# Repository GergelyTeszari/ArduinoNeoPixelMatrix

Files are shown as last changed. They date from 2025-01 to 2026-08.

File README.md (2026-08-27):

# Arduino NeoPixel Matrix

A complete 16 × 16 RGB LED matrix project combining embedded firmware, serial image transfer, a custom desktop pixel-art editor, reusable static pictures, and a 3D-printable enclosure.

The project supports a compiled-in static image and two serial receiver variants for an Arduino Uno-controlled NeoPixel matrix. The repository also contains a Python/Tkinter editor, a curated set of Arduino-ready image snippets, hardware test sketches, and enclosure models.

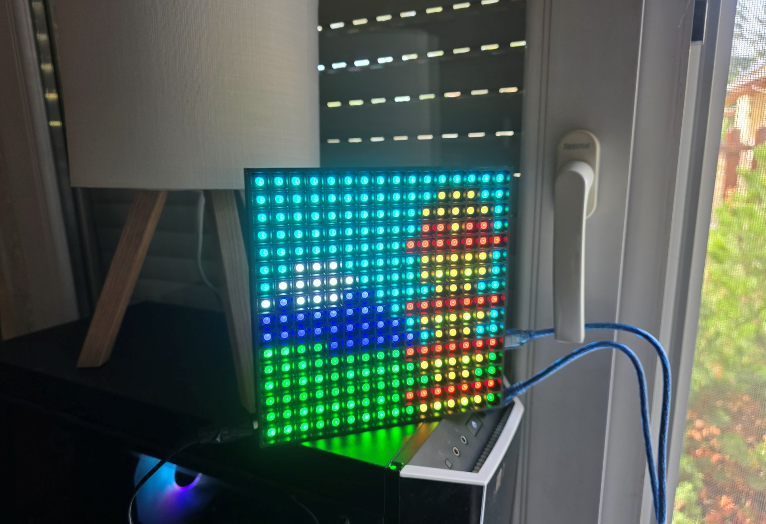
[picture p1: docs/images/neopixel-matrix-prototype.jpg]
16 x 16 NeoPixel matrix prototype displaying Mount Fuji and a pagoda


*The assembled prototype displaying the static Mount Fuji image included with the firmware.*

## Project overview

```mermaid
flowchart LR
    A[Python pixel editor] -->|TXT array rows| B[Static firmware]
    C[Desktop serial sender] -->|Pixel or row protocol| D[Serial firmware]
    B --> E[16 x 16 RGB matrix]
    D --> E
    F[3D-printable enclosure] --> E
```

This project brings together several engineering areas:

- embedded firmware development on Arduino Uno;
- coordinate transformation for a serpentine-wired LED matrix;
- a Python desktop tool for creating pixel art;
- static and serial image transfer workflows;
- custom image-data export and reusable picture sources;
- mechanical design for a printable enclosure and supporting parts.

## Current features

### Arduino firmware

- Controls a 16 × 16, 256-pixel RGB NeoPixel matrix.
- Maps two-dimensional image coordinates to the physical serpentine LED layout.
- Corrects the vertical orientation of the installed matrix.
- Displays a compiled-in static image, currently Mount Fuji and a pagoda.
- Includes a legacy receiver that accepts one `RRGGBB` pixel per serial line.
- Includes an optimized receiver that accepts one 16-pixel row per serial line.
- Includes full-matrix color and individual-pixel diagnostic sketches.
- Uses the Adafruit NeoPixel library.

### Pixel-art editor

The included `tools/pixel_editor/NeoPixel_Matrix_Canvas.py` application provides:

- a 16 × 16 drawing canvas;
- color selection;
- continuous mouse drawing;
- an eraser and canvas reset function;
- global brightness scaling before export;
- export as Arduino C array rows;
- export to the custom `.mtx` text format.

### Mechanical design

The `hardware/enclosure` directory contains STL files for:

- the upper frame and pixel-separating grid;
- the lower enclosure with hardware cut-outs;
- desktop support feet;
- an LED-position alignment template.

The enclosure is an early hardware revision and may require small adjustments depending on the exact matrix PCB and connector placement.

### Static picture gallery

`assets/patterns/txt` contains six 16 × 16 pictures as Arduino initializer rows. Keeping these generated `.txt` snippets makes it possible to replace the static `colorMatrix` without changing the exporter or introducing a build-time conversion step. See [Static image source files](docs/static-images.md).

## Repository structure

```text
ArduinoNeoPixelMatrix/
├── assets/patterns/txt/       # Arduino-ready 16 x 16 image snippets
├── docs/                      # Serial protocol and static image guides
├── examples/                  # Matrix hardware diagnostic sketches
├── firmware/
│   ├── serial/                # Legacy and optimized serial receivers
│   └── static_image/          # Compiled-in image firmware
├── hardware/enclosure/        # 3D-printable STL files
├── tools/pixel_editor/        # Python/Tkinter image editor
├── .gitignore
└── README.md
```

## Requirements

### Firmware

- Arduino Uno or compatible board
- 16 × 16 WS2812/NeoPixel-compatible RGB matrix
- Arduino IDE
- [Adafruit NeoPixel library](https://github.com/adafruit/Adafruit_NeoPixel)
- A suitable external 5 V power supply for the LED matrix

> **Power note:** A 256-pixel RGB matrix can require substantially more current than an Arduino board can safely provide. Power the matrix from a properly rated external supply and connect the supply ground to the Arduino ground.

### Pixel editor

- Python 3
- Tkinter, normally included with standard Python desktop installations

No third-party Python packages are currently required.

## Usage

### Static image workflow

Run the editor from the repository root:

```bash
python tools/pixel_editor/NeoPixel_Matrix_Canvas.py
```

Draw the image, select the required brightness, and choose **Export to TXT**.

The generated `export.txt` file contains the rows of an Arduino-compatible color matrix. Replace the contents of the `colorMatrix` initializer in:

```text
firmware/static_image/NeoPixel_Array/NeoPixel_Array.ino
```

with the exported rows. Existing ready-to-copy pictures are available in `assets/patterns/txt`; their exact format and names are described in [Static image source files](docs/static-images.md).

Open the sketch in Arduino IDE, install the Adafruit NeoPixel library if required, select the correct board and serial port, and upload the firmware.

The included example image is a hand-drawn Mount Fuji scene with a Japanese pagoda.

### Serial image workflow

Choose one of the following sketches:

- `firmware/serial/NeoPixel_Serial/NeoPixel_Serial.ino` receives and displays one pixel per line;
- `firmware/serial/NeoPixel_Serial_optimised/NeoPixel_Serial_optimised.ino` receives and displays one complete 16-pixel row per line.

The two sketches use different wire protocols. Read [Serial firmware and protocol](docs/serial-protocol.md) before implementing or selecting a sender. The optimized version is recommended for normal frame transfer; the legacy version remains available for compatibility and debugging.

### Hardware diagnostics

- `examples/NeoPixel_AllRGB_test/NeoPixel_AllRGB_test.ino` fills the complete matrix with red, green, blue and a pale white test color.
- `examples/NeoPixel_IndividualRGB_test/NeoPixel_IndividualRGB_test.ino` walks through every logical position one at a time in each RGB channel, making wiring-order and mapping errors easier to locate.

## Implementation details

The physical LEDs are arranged in alternating directions. The firmware converts logical `(x, y)` coordinates to the correct physical LED index:

```cpp
int getPixelIndex(int x, int y) {
  int invertedY = 15 - y;

  if (invertedY % 2 == 0) {
    return invertedY * 16 + x;
  }

  return invertedY * 16 + (15 - x);
}
```

This allows the image data to remain stored as a conventional two-dimensional array while the mapping function handles the physical wiring layout.

## Project status and limitations

This repository currently represents a working prototype rather than a finished product.

- The static Arduino firmware displays one image compiled into the sketch.
- Two serial receivers provide pixel-by-pixel and row-by-row image transfer.
- Serial transfer has no acknowledgement, checksum or atomic frame swap.
- The `.mtx` format can be exported by the editor but is not yet loaded by the firmware.
- The editor does not yet reopen existing `.mtx` files.
- Matrix dimensions and hardware pins are currently fixed in the source code.
- The static image representation is memory-intensive for an Arduino Uno.
- The enclosure is a first mechanical revision.

## Planned improvements

- Store image data more efficiently, for example in flash memory.
- Add an automated converter from the maintained TXT snippets to firmware headers.
- Add `.mtx` import to the desktop editor.
- Implement dynamic image loading on an ESP32-based version.
- Add framing, checksums and acknowledgements to serial image transfer.
- Add SD-card image loading.
- Make matrix dimensions, orientation, and pin assignment configurable.
- Add hardware photos, a wiring diagram, and a short demonstration video.
- Add automated checks for the Python exporter, picture dimensions, serial parser and coordinate mapping.

## Background

This is a personal end-to-end embedded project covering firmware, tooling, physical integration, and mechanical prototyping. Its main purpose is to explore how a small embedded product can be supported by purpose-built development tools instead of treating the firmware as an isolated sketch.

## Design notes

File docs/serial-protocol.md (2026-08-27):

# Serial firmware and protocol

The repository contains two Arduino sketches that receive a 16 x 16 RGB image
over a 115200 baud serial connection. Both expect colors in six-character
`RRGGBB` hexadecimal notation and both map ordinary top-left-origin image
coordinates to the installed serpentine matrix wiring.

The protocols are deliberately documented separately because they are not
interchangeable.

## Quick comparison

| Behavior | Legacy receiver | Optimized receiver |
| --- | --- | --- |
| Sketch | `NeoPixel_serial` | `NeoPixel_serial_optimised` |
| Data per line | One pixel, 6 characters | One row, 96 characters |
| Data lines per frame | 256 | 16 |
| `strip.show()` calls per frame | 256 | 16 |
| Reset recognition | Any 10-character line | Exactly `0123456789` |
| Reset clears LEDs | Yes | No |
| Invalid input | Ignored by length | Ignored by length/content |

Use the optimized receiver for normal image transfer. The legacy version is
kept for compatibility with an older sender and is useful when watching an
image arrive one pixel at a time.

## Shared configuration

- Baud rate: `115200`
- Color format: `RRGGBB`, without `#` or separators
- Logical dimensions: 16 columns by 16 rows
- Logical order: top row to bottom row, left to right within each row
- Data pin: Arduino digital pin 6
- LED type: `NEO_GRB + NEO_KHZ800`

For example, the following values represent individual pixels:

```text
FF0000  red
00FF00  green
0000FF  blue
000000  off
FFFFFF  white
```

Although data is expressed as RGB, the Adafruit NeoPixel library handles the
matrix's physical GRB channel order.

## Legacy pixel-by-pixel receiver

Sketch:
`firmware/serial/NeoPixel_Serial/NeoPixel_Serial.ino`

### Starting a frame

Send one line containing exactly ten characters. For compatibility with the
original implementation, the actual characters are not checked. Using the
same token as the optimized protocol is recommended:

```text
0123456789
```

The receiver then:

1. moves its logical write cursor to pixel 0;
2. clears all 256 LEDs;
3. displays the cleared matrix immediately.

### Sending pixels

Send 256 lines. Each line contains exactly one six-character color:

```text
FF0000
00FF00
0000FF
...
```

The first line writes logical coordinate `(0, 0)`, the second `(1, 0)`, and so
on. After `(15, 0)`, the next value writes `(0, 1)`. Each accepted value is
shown immediately. Values sent after the 256th pixel are ignored until another
reset line arrives.

The legacy sketch accepts either LF or CRLF line endings. It uses Arduino
`String` and refreshes after every pixel, so it is less memory- and
bandwidth-efficient than the optimized version.

## Optimized row-by-row receiver

Sketch:
`firmware/serial/NeoPixel_Serial_optimised/NeoPixel_Serial_optimised.ino`

### Starting a frame

Send this exact line:

```text
0123456789
```

This resets the logical row cursor to row 0. It intentionally does not clear
the LEDs, allowing the old image to remain visible while the new frame arrives.

### Sending rows

Send exactly 16 lines after the reset. Each line contains 16 adjacent `RRGGBB`
values with no spaces or separators, for a total of 96 characters:

```text
FF000000FF000000FF000000FF000000FF000000FF000000FF000000FFFFFF
```

That example is one row containing 16 pixels. The firmware validates the row
length and hexadecimal characters, fills all 16 pixels, then calls
`strip.show()` once. Invalid rows are ignored without advancing the row cursor.

After 16 valid rows, further row data is ignored until the reset command is
received. Both LF and CRLF line endings are accepted.

## Minimal Python sender outline

The important part of a sender is to preserve row-major ordering and terminate
every command or data record with a newline:

```python
serial_port.write(b"0123456789\n")

for row in image_rows:
    line = "".join(f"{red:02X}{green:02X}{blue:02X}"
                   for red, green, blue in row)
    serial_port.write((line + "\n").encode("ascii"))
```

For the legacy receiver, iterate over every pixel and send each formatted color
as its own line instead.

## Current protocol limitations

- There is no acknowledgement from the Arduino.
- There is no checksum or frame number.
- A malformed legacy six-character value is not fully validated.
- The optimized receiver displays each completed row rather than swapping a
  complete frame atomically.
- Matrix size, data pin and baud rate are compile-time constants.

These constraints are acceptable for a direct USB serial prototype but should
be revisited before using an unreliable transport or continuous animation.

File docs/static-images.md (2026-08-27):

# Static image source files

The files in `assets/patterns/txt` are editable source snippets for the static
Arduino firmware. They are intentionally kept as `.txt` files so a picture can
be copied directly into the `colorMatrix` initializer without running a
conversion tool.

## File format

Each image contains 16 non-empty lines. Every line contains 16 expressions in
this form:

```cpp
strip.Color(red, green, blue)
```

The lines are the rows of a conventional 16 x 16 image, from top to bottom.
The matrix mapping function in the firmware handles the physical bottom-up,
serpentine wiring.

The files contain only the initializer rows, not the declaration around them.
Copy a complete file between the braces here:

```cpp
uint32_t colorMatrix[16][16] = {
  // Paste the .txt file here.
};
```

The matching sketch is:
`firmware/static_image/NeoPixel_Array/NeoPixel_Array.ino`.

## Included pictures

| File | Original local name | Subject |
| --- | --- | --- |
| `frog.txt` | `beka.txt` | Frog |
| `mount_fuji.txt` | `Fuji1.txt` | Mount Fuji and pagoda |
| `mario.txt` | `mario.txt` | Mario |
| `fox.txt` | `roka.txt` | Fox |
| `sakura.txt` | `sakura1.txt` | Sakura scene |
| `smurf_with_spear.txt` | `torp_dardaval.txt` | Smurf with a spear |

The current static firmware contains the same pixel values as
`mount_fuji.txt`.

## Creating or updating a picture

Run the Tkinter editor from the repository root:

```bash
python tools/pixel_editor/NeoPixel_Matrix_Canvas.py
```

Choose **Export to TXT**. The editor writes `export.txt` to the current working
directory. Check that it contains 16 rows with 16 colors per row, rename it to
a descriptive lowercase filename, and place it in `assets/patterns/txt`.

The generic `export.txt` and `export.mtx` output names are ignored by Git so an
accidental export is not committed as a new asset.

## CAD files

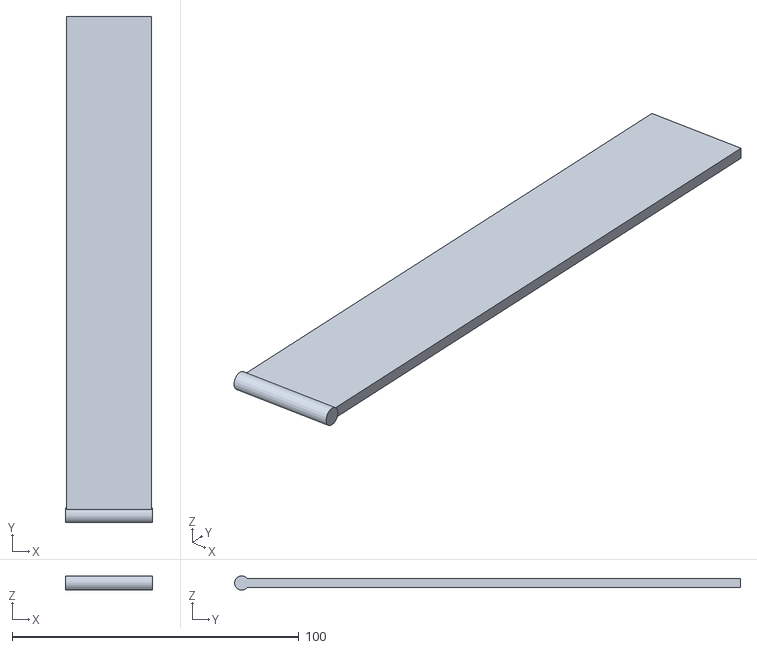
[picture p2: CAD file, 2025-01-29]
hardware/enclosure/Feet.stl
30.5 x 176.5 x 5.00

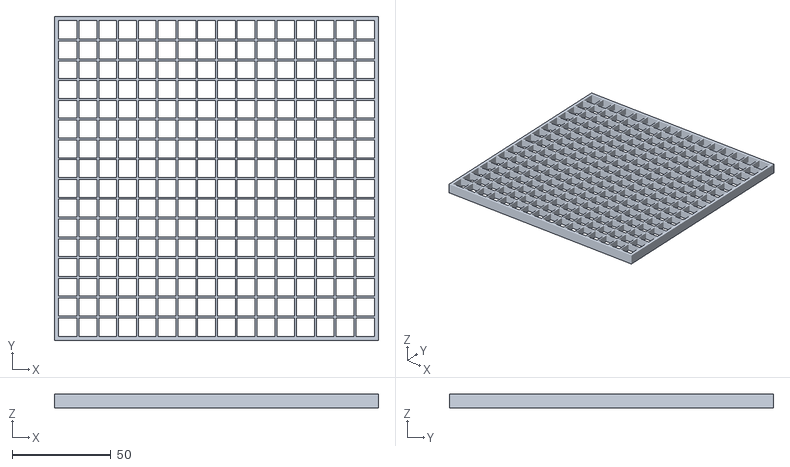
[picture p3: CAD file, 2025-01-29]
hardware/enclosure/NeoPixel_Matrix_frame_top_frame_with_grid.stl
164.0 x 164.0 x 7.00

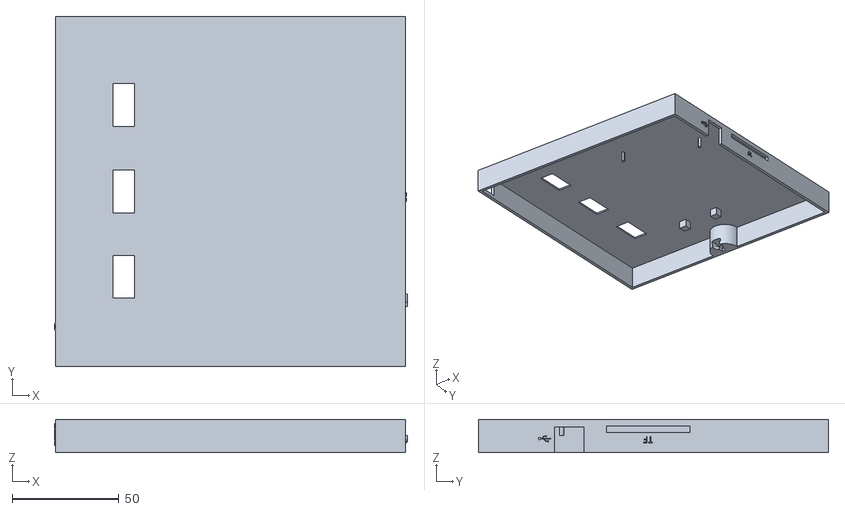
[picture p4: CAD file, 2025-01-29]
hardware/enclosure/NeoPixel_Matrix_frame_bottom_frame.stl
165.5 x 164.0 x 15.5

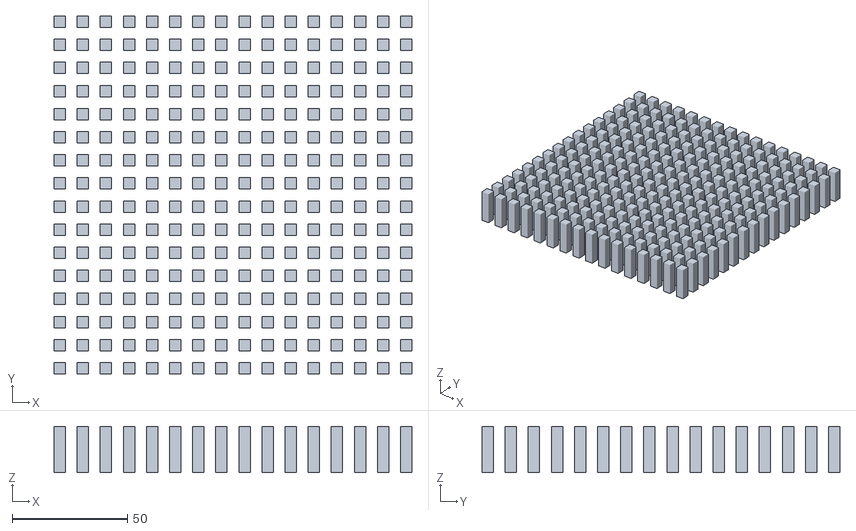
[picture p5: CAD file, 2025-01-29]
hardware/enclosure/LED_positions.stl
155.0 x 155.0 x 20.0

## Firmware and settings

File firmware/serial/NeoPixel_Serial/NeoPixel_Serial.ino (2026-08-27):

#include <Adafruit_NeoPixel.h>

// Hardware configuration for the 16 x 16 matrix.
constexpr uint8_t DATA_PIN = 6;
constexpr uint8_t MATRIX_WIDTH = 16;
constexpr uint8_t MATRIX_HEIGHT = 16;
constexpr uint16_t NUM_PIXELS = MATRIX_WIDTH * MATRIX_HEIGHT;
constexpr unsigned long SERIAL_BAUD_RATE = 115200;

// The legacy protocol receives one six-character RRGGBB value per line.
// Historically, any ten-character line has acted as a frame reset command.
constexpr uint8_t PIXEL_HEX_LENGTH = 6;
constexpr uint8_t RESET_MESSAGE_LENGTH = 10;

Adafruit_NeoPixel strip(NUM_PIXELS, DATA_PIN, NEO_GRB + NEO_KHZ800);

// Index of the next logical pixel in row-major image order.
uint16_t nextPixel = 0;

// Convert an image coordinate to the physical LED number.
//
// The matrix is installed bottom-to-top and wired in a serpentine (snake)
// pattern. Image data can therefore stay in conventional top-left origin,
// left-to-right row order while this function handles the wiring layout.
uint16_t getPixelIndex(uint8_t x, uint8_t y) {
  uint8_t invertedY = MATRIX_HEIGHT - 1 - y;

  if (invertedY % 2 == 0) {
    return invertedY * MATRIX_WIDTH + x;
  }

  return invertedY * MATRIX_WIDTH + (MATRIX_WIDTH - 1 - x);
}

void clearMatrix() {
  for (uint16_t i = 0; i < NUM_PIXELS; i++) {
    strip.setPixelColor(i, 0);
  }
  strip.show();
}

void displayNextPixel(const String &hexColor) {
  // Interpret the six input characters as one 24-bit RRGGBB value.
  unsigned long color = strtoul(hexColor.c_str(), nullptr, 16);
  uint8_t red = (color >> 16) & 0xFF;
  uint8_t green = (color >> 8) & 0xFF;
  uint8_t blue = color & 0xFF;

  uint8_t x = nextPixel % MATRIX_WIDTH;
  uint8_t y = nextPixel / MATRIX_WIDTH;
  uint16_t physicalIndex = getPixelIndex(x, y);

  strip.setPixelColor(physicalIndex, strip.Color(red, green, blue));

  // This is intentionally immediate in the legacy implementation. It makes
  // the incoming image visible pixel by pixel, but is slower than the row-based
  // optimized receiver.
  strip.show();
  nextPixel++;
}

void processSerialLine(const String &line) {
  if (line.length() == RESET_MESSAGE_LENGTH) {
    // Legacy compatibility: the original sketch treated any ten-character
    // line as reset. It clears the LEDs and restarts at logical pixel (0, 0).
    nextPixel = 0;
    clearMatrix();
    return;
  }

  if (line.length() == PIXEL_HEX_LENGTH && nextPixel < NUM_PIXELS) {
    displayNextPixel(line);
  }

  // Empty, malformed and excess pixel lines are ignored.
}

void setup() {
  strip.begin();
  strip.show();  // Start with all LEDs off.
  Serial.begin(SERIAL_BAUD_RATE);
}

void loop() {
  static String input;

  while (Serial.available()) {
    char character = Serial.read();

    // Both LF and CR are accepted as line endings. With CRLF, the second
    // character produces an empty line, which processSerialLine ignores.
    if (character == '\n' || character == '\r') {
      processSerialLine(input);
      input = "";
      continue;
    }

    input += character;

    // Recover automatically if a sender transmits an unexpectedly long line.
    if (input.length() > 16) {
      input = "";
    }
  }
}

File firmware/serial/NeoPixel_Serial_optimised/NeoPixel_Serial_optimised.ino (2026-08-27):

#include <Adafruit_NeoPixel.h>

// Hardware configuration for the 16 x 16 matrix.
constexpr uint8_t DATA_PIN = 6;
constexpr uint8_t MATRIX_WIDTH = 16;
constexpr uint8_t MATRIX_HEIGHT = 16;
constexpr uint16_t NUM_PIXELS = MATRIX_WIDTH * MATRIX_HEIGHT;
constexpr unsigned long SERIAL_BAUD_RATE = 115200;

// One protocol line represents one complete matrix row:
// 16 pixels x 6 hexadecimal RRGGBB characters = 96 characters.
constexpr size_t HEX_CHARACTERS_PER_PIXEL = 6;
constexpr size_t ROW_HEX_LENGTH = MATRIX_WIDTH * HEX_CHARACTERS_PER_PIXEL;
constexpr char RESET_COMMAND[] = "0123456789";

Adafruit_NeoPixel strip(NUM_PIXELS, DATA_PIN, NEO_GRB + NEO_KHZ800);

// Convert a conventional image coordinate to the physical LED number.
// The matrix is mounted bottom-to-top and wired in alternating directions.
uint16_t getPixelIndex(uint8_t x, uint8_t y) {
  uint8_t invertedY = MATRIX_HEIGHT - 1 - y;

  if (invertedY % 2 == 0) {
    return invertedY * MATRIX_WIDTH + x;
  }

  return invertedY * MATRIX_WIDTH + (MATRIX_WIDTH - 1 - x);
}

bool isHexCharacter(char character) {
  return (character >= '0' && character <= '9') ||
         (character >= 'a' && character <= 'f') ||
         (character >= 'A' && character <= 'F');
}

bool isValidPixelRow(const char *row, size_t length) {
  if (length != ROW_HEX_LENGTH) {
    return false;
  }

  for (size_t i = 0; i < length; i++) {
    if (!isHexCharacter(row[i])) {
      return false;
    }
  }

  return true;
}

uint8_t parseHexByte(char highNibble, char lowNibble) {
  char byteText[3] = {highNibble, lowNibble, '\0'};
  return static_cast<uint8_t>(strtoul(byteText, nullptr, 16));
}

void displayRow(const char *rowData, uint8_t logicalY) {
  for (uint8_t x = 0; x < MATRIX_WIDTH; x++) {
    size_t offset = x * HEX_CHARACTERS_PER_PIXEL;
    uint8_t red = parseHexByte(rowData[offset], rowData[offset + 1]);
    uint8_t green = parseHexByte(rowData[offset + 2], rowData[offset + 3]);
    uint8_t blue = parseHexByte(rowData[offset + 4], rowData[offset + 5]);

    uint16_t physicalIndex = getPixelIndex(x, logicalY);
    strip.setPixelColor(physicalIndex, strip.Color(red, green, blue));
  }

  // Updating once per row is the main speed improvement over the legacy
  // receiver, which calls show() after every individual pixel.
  strip.show();
}

void setup() {
  strip.begin();
  strip.show();  // Start with all LEDs off.
  Serial.begin(SERIAL_BAUD_RATE);
}

void loop() {
  // Extra space allows an optional carriage return before the terminating LF.
  static char inputBuffer[ROW_HEX_LENGTH + 2];
  static uint8_t currentRow = 0;

  if (!Serial.available()) {
    return;
  }

  size_t bytesRead = Serial.readBytesUntil(
      '\n', inputBuffer, sizeof(inputBuffer) - 1);

  // Accept both LF and CRLF senders by removing a trailing carriage return.
  if (bytesRead > 0 && inputBuffer[bytesRead - 1] == '\r') {
    bytesRead--;
  }
  inputBuffer[bytesRead] = '\0';

  if (bytesRead == sizeof(RESET_COMMAND) - 1 &&
      strcmp(inputBuffer, RESET_COMMAND) == 0) {
    // The optimized reset only moves the write cursor to row zero. It does not
    // clear the already displayed pixels; the following rows overwrite them.
    currentRow = 0;
    return;
  }

  // A frame contains exactly 16 rows. Further rows are ignored until RESET.
  if (currentRow >= MATRIX_HEIGHT) {
    return;
  }

  if (!isValidPixelRow(inputBuffer, bytesRead)) {
    return;
  }

  displayRow(inputBuffer, currentRow);
  currentRow++;
}

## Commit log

2025-01-29 Drawing script for the matrix, V2
    This script is responsible for generating images for the matrix display.
    V2 is capable of outputting .mtx, which will be the official supported file format.
    Furthermore, it can output a C array to a .txt file, in order to be able to copy and paste static images to the Arduino code.
    Script is AI generated for the most part.
2025-01-29 Static image display
    This Arduino script is capable of displaying a static image.
    The image can be modifyed by re-flashing the Arduino, and swapped by the generated output of the NeoPixel_Matrix_Canvas.py, when exporting the image to .txt.
    Initial contained picture within the script is a scenry of Mt. Fuji, with a Japanese pagoda at the right (drawn by me for testing purpose).
    [NeoPixel_Array.ino]
2025-01-29 3d models, Rev1
    These are the .stl files required for the matrix frame. (Rev 1)
    Feet.stl: prop-up feet for the frame to be able to stand on a desktop (requires drilling a hole in the frame, and in the feet, and connecting these together with a string, on the bottom).
    LED_positions.stl: template for checking the LEDs' positions inside the grid
    NeoPixel_Matrix_frame_bottom_frame.stl: bottom half of the frame, enclosing an Arduino Uno on meltable pegs, with proper USB cutout, SD (not micro SD) cutout, and a cutout for the DC 5V barrel jack. The three cutouts on the bottom are for the solder point on the matrix PCB's back, the two little cubes are for holding the feet. The cutouts are labeled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
    [Feet.stl, LED_positions.stl, NeoPixel_Matrix_frame_bottom_frame.stl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]
2026-08-27 refactor: organize project files by purpose
    [Feet.stl, LED_positions.stl, NeoPixel_Matrix_frame_bottom_frame.stl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]
2026-08-27 docs: add prototype photo to README
